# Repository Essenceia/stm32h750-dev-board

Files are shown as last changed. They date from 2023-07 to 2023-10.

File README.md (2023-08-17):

# 10 year Anniversary developpement board

Minimal custom arm m7 devloppement board designed as a 10 year anniversary present. 

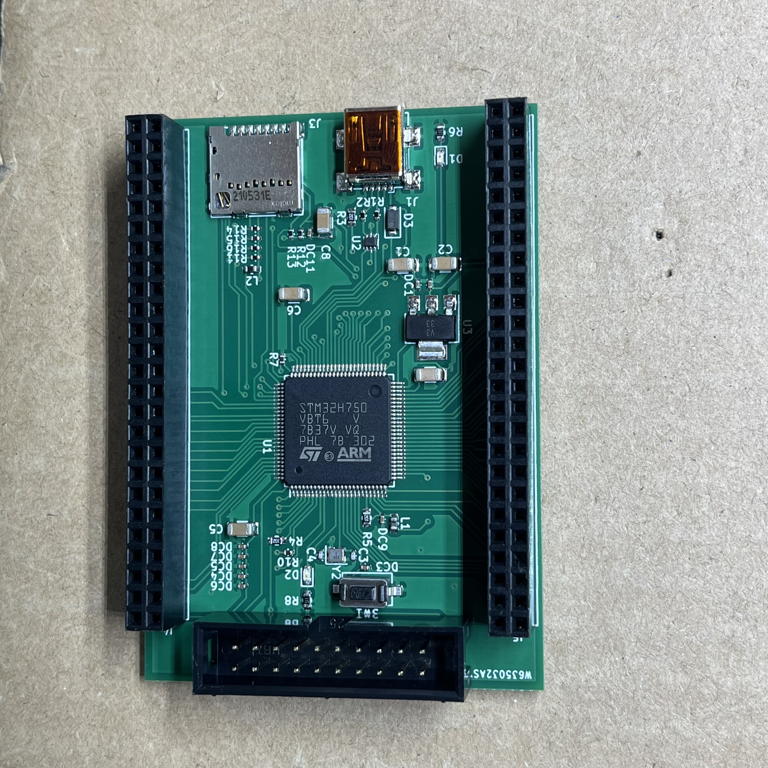
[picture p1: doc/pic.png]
picture!


Selected MCU : STM32H750VBT6TR 

MCU package :  LQFP-100 

Requirements :

- SWD debug connected with pinout compatible with native 20 pin J-Link probe

- Route all remaining mcu pins to female connectors 

## Schematics

Schematic : [schematics](/doc/schematic.pdf)

## PCB

Resulting pcb, front : 

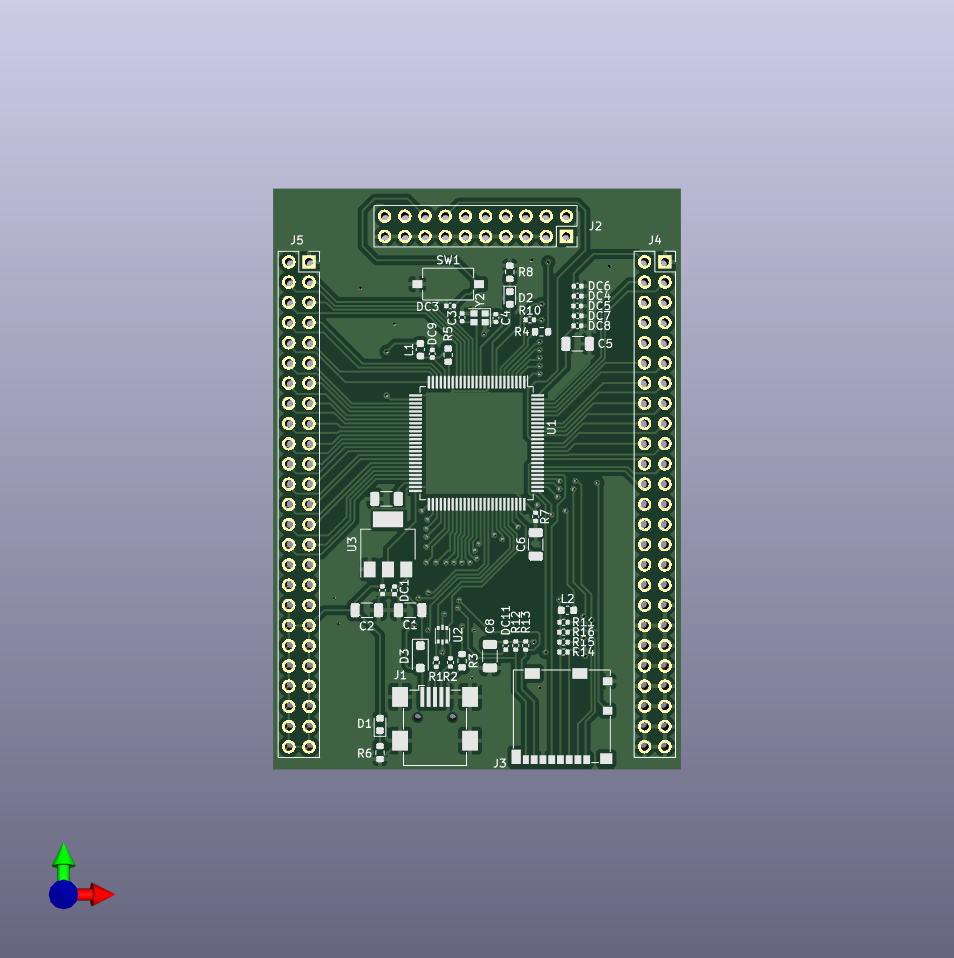
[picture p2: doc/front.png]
fount!


back :

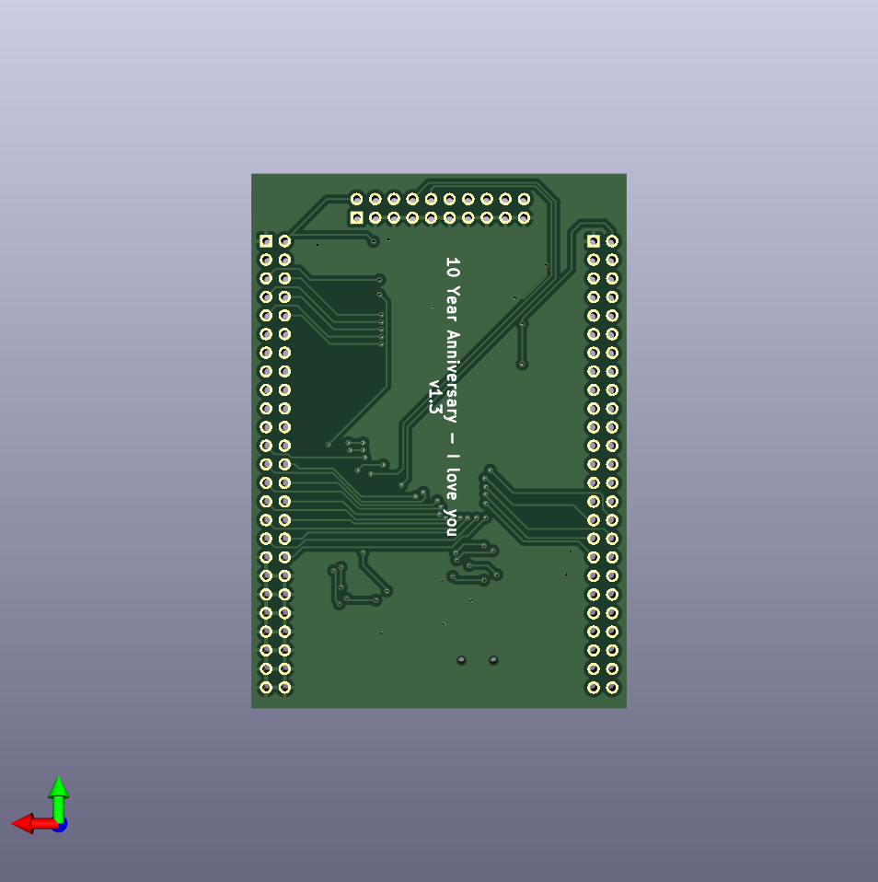
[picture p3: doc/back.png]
back!


## SWD - J-Link

SWD Connector Pinout:
connector!

The following table lists the J-Link / J-Trace SWD pinout.
|Pin|Signal|Type|Description|
|---|---|----|---|
|1|VTref|Input|This is the target reference voltage. It is used to check if the target has power, to create the logic-level reference for the input comparators and to control the output logic levels to the target. It is normally fed from Vdd of the target board and must not have a series resistor.|
|2|Vsupply|NC|This pin is not connected in J-Link. It is reserved for compatibility with other equipment. Connect to Vdd or leave open in target system.|
|3|Not used|NC|This pin is not used by J-Link. If the device may also be accessed via JTAG, this pin may be connected to nTRST, otherwise leave open.|
|5|Not used|NC|This pin is not used by J-Link. If the device may also be accessed via JTAG, this pin may be connected to TDI, otherwise leave open.|
|7|SWDIO|I/O|Single bi-directional data pin.|
|9|SWCLK|Output|Clock signal to target CPU. It is recommended that this pin is pulled to a defined state of the target board. Typically connected to TCK of target CPU.|
|11|Not used|NC|This pin is not used by J-Link. This pin is not used by J-Link when operating in SWD mode. If the device may also be accessed via JTAG, this pin may be connected to RTCK, otherwise leave open.|
|13|SWO|Input|Serial Wire Output trace port. (Optional, not required for SWD communication.)|
|15|nRESET|I/O|Target CPU reset signal. Typically connected to the RESET pin of the target CPU, which is typically called "nRST", "nRESET" or "RESET". This signal is an active low signal.|
|17|Not used|NC|This pin is not connected in J-Link.|
|19|5V-Supply|Output|This pin is used to supply power to some eval boards.|

Pins 4, 6, 8, 10, 12, 14, 16, 18, 20 are GND pins connected to GND in J-Link. They should also be connected to GND in the target system.

## Future improvements ideas

- After adding support for USB 3.0 and up switch usb b mini for thunderbolt

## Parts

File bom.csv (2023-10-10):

Item # | Designator | Qty | Manufacturer | Mfg Part # | Description / Value | Package/Footprint | Type | Your Instructions / Notes
1 | DC6,DC3,DC5,DC4,DC8,DC9,DC7,DC11,DC1,DC2 | 10 | KEMET | C0402C104K4RAC | 100nF | 0402 | SMD
2 | U3 | 1 | Texas Instruments | TLV1117-33CDCYRG3 | TLV1117-33 | SOT-223 | SMD
3 | R4,R5,R3 | 3 | SEI Stackpole | RMCF0603JJ1K00 | 1k | 0603 | SMD
4 | Y2 | 1 | ECS Inc. | ECS-250-9-37B2-CKM-TR | 25MHz 9uF | 2.0x1.6mm | SMD
5 | R15,R14,R13,R7,R16,R12,R10,R11 | 8 | YAGEO | RC0402FR-0710KL | 10k | 0402 | SMD
6 | U1 | 1 | STMicroelectronics | STM32H750VBT6TR / STM32H742VIT6 | STM32H750VBTx / STM32H742VI | LQFP-100 | QFP | MCU for v1 and v2, pin compatible
7 | J2 | 1 | On Shore Technology Inc. | 302-S201 | Conn_ARM_JTAG_SWD_20 | THD | Through Hole
8 | C8,C5,C6,C7,C1,C2 | 6 | Samsung Electro-Mechanics | CL31A476MQHNNNE | 47uF/3528 | 1206 | SMD
9 | D2,D1 | 2 | EVERLIGHT | 19-213SYGC/S530-E2/5T | LED | 0603 | SMD
10 | R1,R2 | 2 | YAGEO | RC0402FR-0722RL | 22 | 0402 | SMD
11 | R6,R8 | 2 | SEI Stackpole | RMCA0603JT510R | 510 | 0603 | SMD
12 | C4,C3 | 2 | Murata Electronics | GJM1555C1H8R0DB01D | 8pF | 0402 | SMD
13 | J3 | 1 | Molex | 1040310811 | Micro_SD_Card_Det1 |  | SMD
14 | D3 | 1 | Toshiba | CRS30I40A(TE85L,QM | SS34 | SOD-123F | SMD
15 | L1,L2 | 2 | TAI-TECH | FCM1608KF-102T02 | 1KB | 0603 | SMD
16 | SW1 | 1 | C&K | PTS636 SM43 SMTR LFS | SW_RESET | 6.0x3.5mm | SMD
17 | U2 | 1 | STMicroelectronics | USBLC6-2P6 | USBLC6-2P6 | SOT-666 | SMD
18 | J1 | 1 | Adam Tech | MUSB-B5-S-RA-SMT-PP-T/R | USB_B_Mini |  | SMD
19 | J4,J5 | 2 | Sullins Connector Solutions | PPTC252LFBN-RC | Conn_02x25_Odd_Even |  | Through Hole

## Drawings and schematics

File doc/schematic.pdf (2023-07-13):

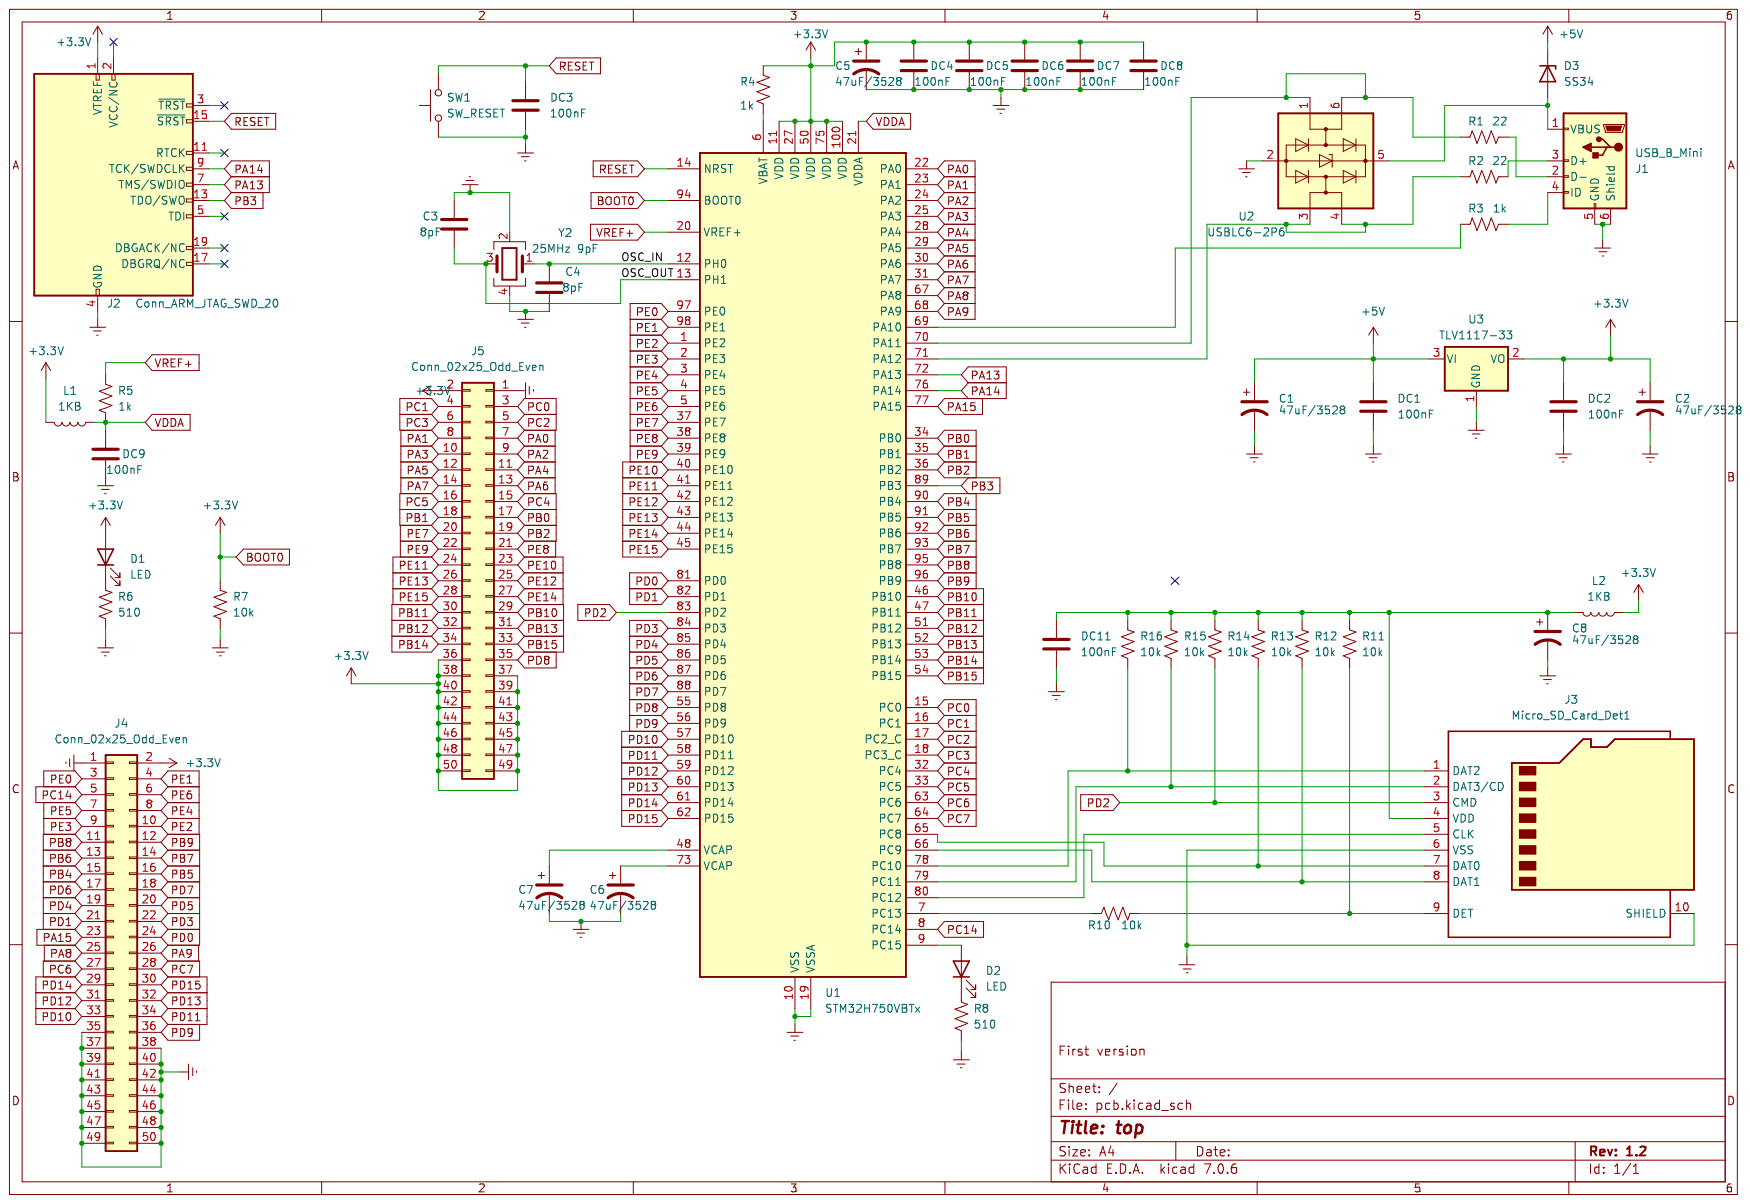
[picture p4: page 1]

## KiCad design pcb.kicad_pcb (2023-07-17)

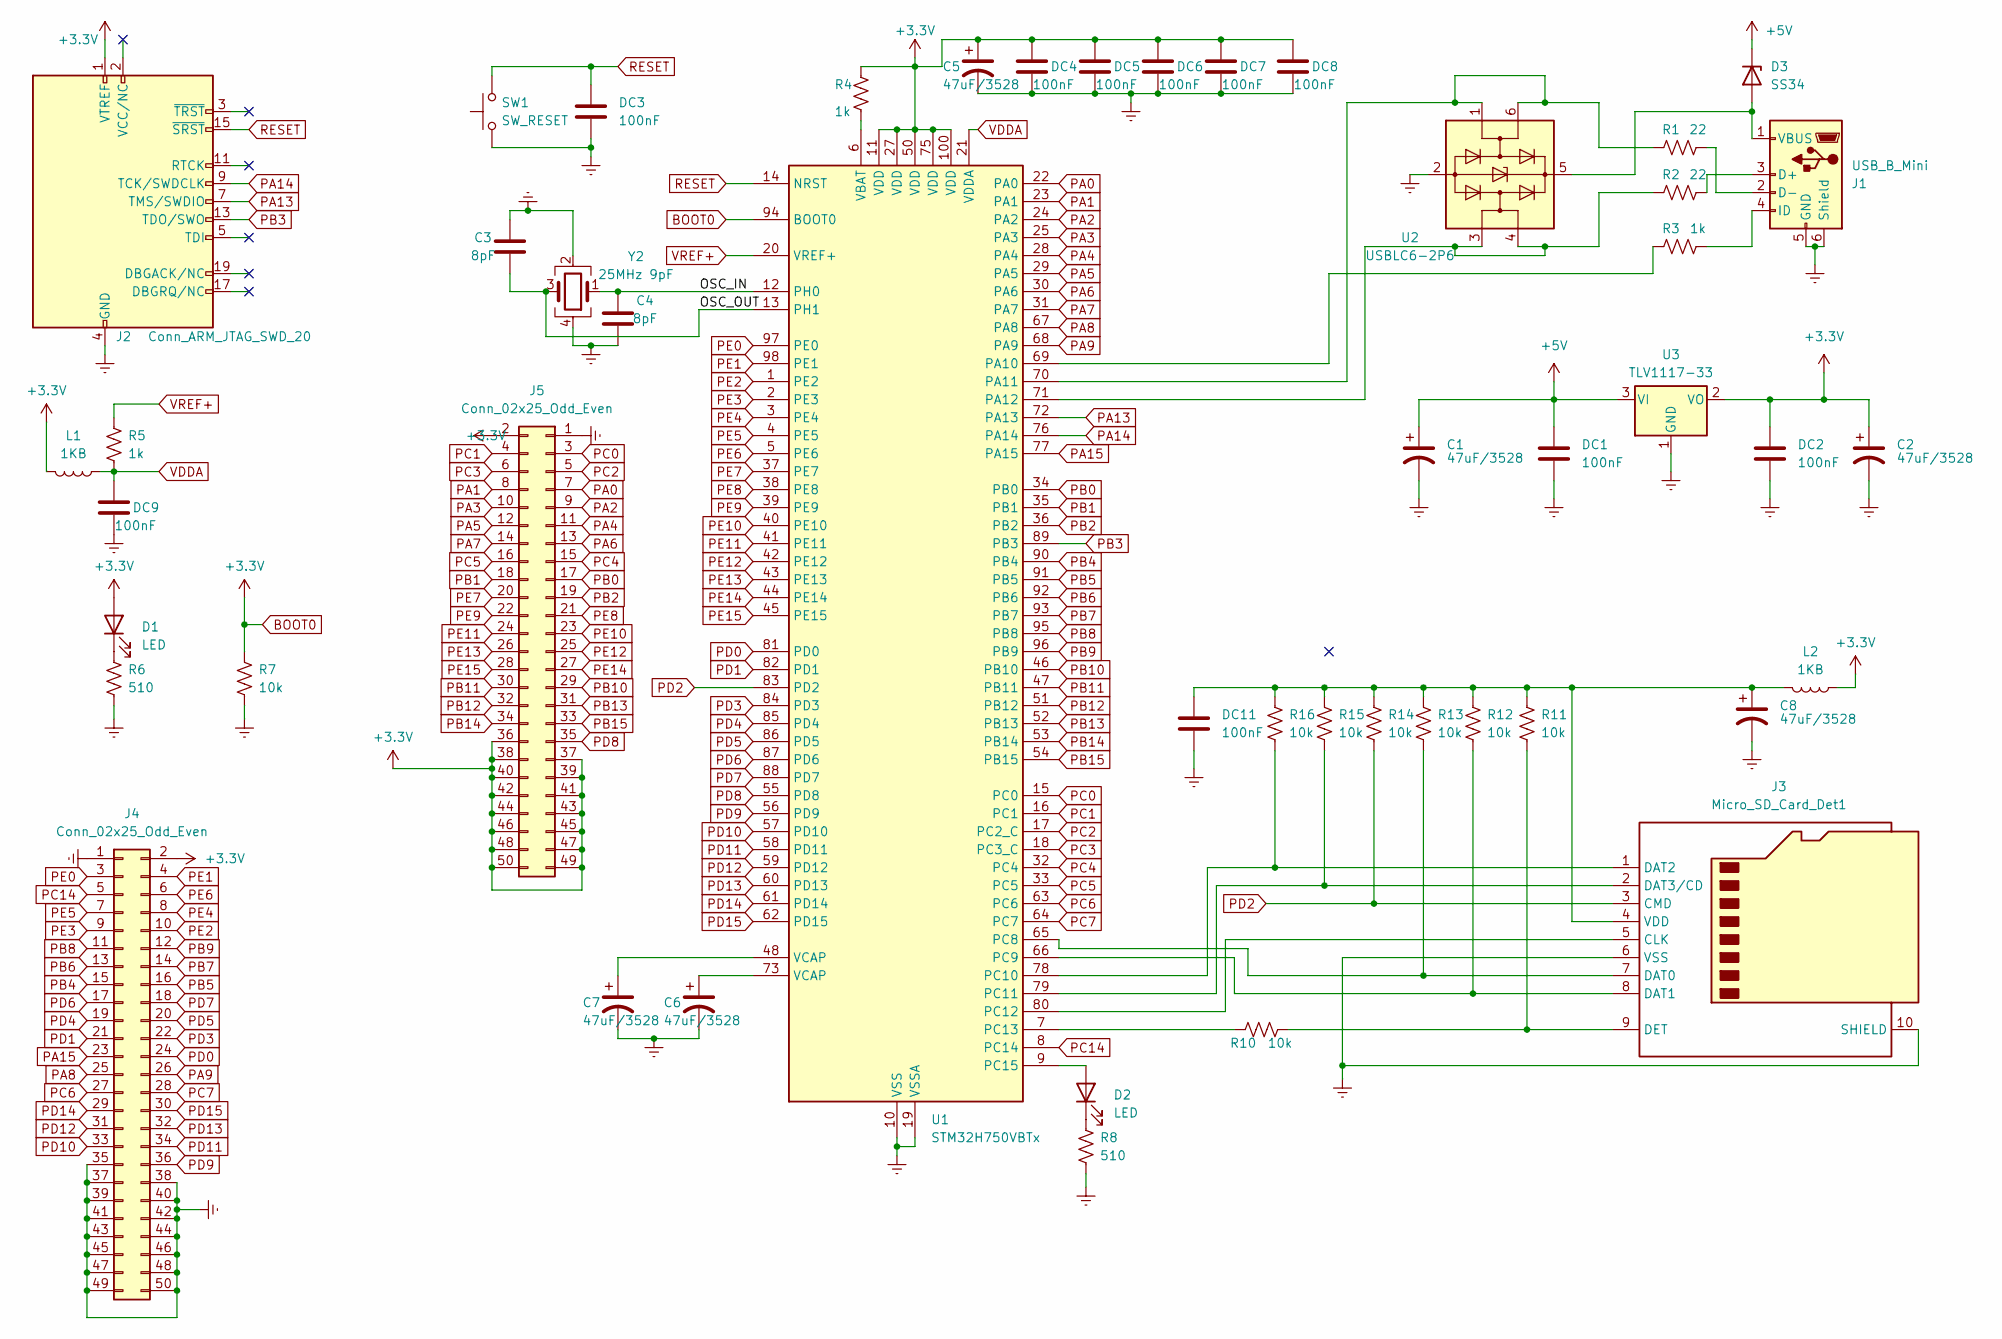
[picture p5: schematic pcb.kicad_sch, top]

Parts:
C1, C2, C5, C6, C7, C8: 47uF/3528; C_1206_3216Metric
C3, C4: 8pF; C_0402_1005Metric
D1, D2: LED; LED_0603_1608Metric
D3: SS34; D_SOD-123F
DC1, DC2, DC3, DC4, DC5, DC6, DC7, DC8, DC9, DC11: 100nF; C_0402_1005Metric
J1: USB_B_Mini; USB_Mini-B_Wuerth_65100516121_Horizontal
J2: Conn_ARM_JTAG_SWD_20; PinSocket_2x10_P2.54mm_Vertical
J3: Micro_SD_Card_Det1; microSD_HC_Molex_104031-0811
J4, J5: Conn_02x25_Odd_Even; PinSocket_2x25_P2.54mm_Vertical
L1, L2: 1KB; L_0603_1608Metric
R1, R2: 22; R_0402_1005Metric
R3, R4, R5: 1k; R_0603_1608Metric
R6, R8: 510; R_0603_1608Metric
R7, R10, R11, R12, R13, R14, R15, R16: 10k; R_0402_1005Metric
SW1: SW_RESET; SW_Tactile_SPST_NO_Straight_CK_PTS636Sx25SMTRLFS
U1: STM32H750VBTx; LQFP-100_14x14mm_P0.5mm
U2: USBLC6-2P6; SOT-666
U3: TLV1117-33; SOT-223
Y2: 25MHz 9pF; Crystal_SMD_2016-4Pin_2.0x1.6mm

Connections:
+5V: C1.1, D3.1 (K), DC1.1, U3.3 (VI)
/OSC_IN: C4.1, U1.12 (PH0), Y2.1
/OSC_OUT: C3.2, U1.13 (PH1), Y2.3
BOOT0: C2.1, C5.1, D1.2 (A), DC2.1, DC4.1, DC5.1, DC6.1, DC7.1, DC8.1, J2.1 (VTREF), J4.2, J5.2, J5.36, J5.37, J5.38, J5.39, J5.40, J5.41, J5.42, J5.43, J5.44, J5.45, J5.46, J5.47, J5.48, J5.49, J5.50, L1.2, L2.2, R4.1, R7.1, U1.11 (VDD), U1.27 (VDD), U1.50 (VDD), U1.75 (VDD), U1.94 (BOOT0), U1.100 (VDD), U3.2 (VO)
Earth: C1.2, C2.2, C3.1, C4.2, C5.2, C6.2, C7.2, C8.2, DC1.2, DC2.2, DC3.2, DC4.2, DC5.2, DC6.2, DC7.2, DC8.2, DC9.2, DC11.2, J1.5 (GND), J1.6 (Shield), J2.4 (GND), J2.6 (GND), J2.8 (GND), J2.10 (GND), J2.12 (GND), J2.14 (GND), J2.16 (GND), J2.18 (GND), J2.20 (GND), J3.6 (VSS), J3.10 (SHIELD), J4.1, J4.35, J4.37, J4.38, J4.39, J4.40, J4.41, J4.42, J4.43, J4.44, J4.45, J4.46, J4.47, J4.48, J4.49, J4.50, J5.1, R6.2, R7.2, R8.2, SW1.1, U1.10 (VSS), U1.19 (VSSA), U1.26 (VSS), U1.49 (VSS), U1.74 (VSS), U1.99 (VSS), U2.2 (GND), U3.1 (GND), Y2.2, Y2.4
unnamed: C6.1, U1.73 (VCAP)
unnamed: C7.1, U1.48 (VCAP)
unnamed: D1.1 (K), R6.1
unnamed: D2.2 (A), U1.9 (PC15)
unnamed: D2.1 (K), R8.1
unnamed: D3.2 (A), J1.1 (VBUS), U2.5 (VBUS)
unnamed: J1.3 (D+), R2.2
unnamed: J1.2 (D-), R1.2
unnamed: J1.4 (ID), R3.2
unnamed: J3.5 (CLK), U1.80 (PC12)
unnamed: J3.7 (DAT0), R13.2, U1.65 (PC8)
unnamed: J3.8 (DAT1), R12.2, U1.66 (PC9)
unnamed: J3.1 (DAT2), R16.2, U1.78 (PC10)
unnamed: J3.2 (DAT3/CD), R15.2, U1.79 (PC11)
unnamed: J3.9 (DET), R10.2, R11.2
unnamed: C8.1, DC11.1, J3.4 (VDD), L2.1, R11.1, R12.1, R13.1, R14.1, R15.1, R16.1
unnamed: R3.1, U1.69 (PA10)
unnamed: R1.1, U1.70 (PA11), U2.1 (I/O1), U2.6 (I/O1)
unnamed: R2.1, U1.71 (PA12), U2.3 (I/O2), U2.4 (I/O2)
unnamed: R10.1, U1.7 (PC13)
unnamed: R4.2, U1.6 (VBAT)
PA0: J5.7, U1.22 (PA0)
PA1: J5.8, U1.23 (PA1)
PA2: J5.9, U1.24 (PA2)
PA3: J5.10, U1.25 (PA3)
PA4: J5.11, U1.28 (PA4)
PA5: J5.12, U1.29 (PA5)
PA6: J5.13, U1.30 (PA6)
PA7: J5.14, U1.31 (PA7)
PA8: J4.25, U1.67 (PA8)
PA9: J4.26, U1.68 (PA9)
PA13: J2.7 (TMS/SWDIO), U1.72 (PA13)
PA14: J2.9 (TCK/SWDCLK), U1.76 (PA14)
PA15: J4.23, U1.77 (PA15)
PB0: J5.17, U1.34 (PB0)
PB1: J5.18, U1.35 (PB1)
PB2: J5.19, U1.36 (PB2)
PB3: J2.13 (TDO/SWO), U1.89 (PB3)
PB4: J4.15, U1.90 (PB4)
PB5: J4.16, U1.91 (PB5)
PB6: J4.13, U1.92 (PB6)
PB7: J4.14, U1.93 (PB7)
PB8: J4.11, U1.95 (PB8)
PB9: J4.12, U1.96 (PB9)
PB10: J5.29, U1.46 (PB10)
PB11: J5.30, U1.47 (PB11)
PB12: J5.32, U1.51 (PB12)
PB13: J5.31, U1.52 (PB13)
PB14: J5.34, U1.53 (PB14)
PB15: J5.33, U1.54 (PB15)
PC0: J5.3, U1.15 (PC0)
PC1: J5.4, U1.16 (PC1)
PC2: J5.5, U1.17 (PC2_C)
PC3: J5.6, U1.18 (PC3_C)
PC4: J5.15, U1.32 (PC4)
PC5: J5.16, U1.33 (PC5)
PC6: J4.27, U1.63 (PC6)
PC7: J4.28, U1.64 (PC7)
PC14: J4.5, U1.8 (PC14)
PD0: J4.24, U1.81 (PD0)
PD1: J4.21, U1.82 (PD1)
PD2: J3.3 (CMD), R14.2, U1.83 (PD2)
PD3: J4.22, U1.84 (PD3)
PD4: J4.19, U1.85 (PD4)
PD5: J4.20, U1.86 (PD5)
PD6: J4.17, U1.87 (PD6)
PD7: J4.18, U1.88 (PD7)
PD8: J5.35, U1.55 (PD8)
PD9: J4.36, U1.56 (PD9)
PD10: J4.33, U1.57 (PD10)
PD11: J4.34, U1.58 (PD11)
PD12: J4.31, U1.59 (PD12)
PD13: J4.32, U1.60 (PD13)
PD14: J4.29, U1.61 (PD14)
PD15: J4.30, U1.62 (PD15)
PE0: J4.3, U1.97 (PE0)
PE1: J4.4, U1.98 (PE1)
PE2: J4.10, U1.1 (PE2)
PE3: J4.9, U1.2 (PE3)
PE4: J4.8, U1.3 (PE4)
PE5: J4.7, U1.4 (PE5)
PE6: J4.6, U1.5 (PE6)
PE7: J5.20, U1.37 (PE7)
PE8: J5.21, U1.38 (PE8)
PE9: J5.22, U1.39 (PE9)
PE10: J5.23, U1.40 (PE10)
PE11: J5.24, U1.41 (PE11)
PE12: J5.25, U1.42 (PE12)
PE13: J5.26, U1.43 (PE13)
PE14: J5.27, U1.44 (PE14)
PE15: J5.28, U1.45 (PE15)
RESET: DC3.1, J2.15 (~SRST), SW1.2, U1.14 (NRST)
VDDA: DC9.1, L1.1, R5.2, U1.21 (VDDA)
VREF+: R5.1, U1.20 (VREF+)

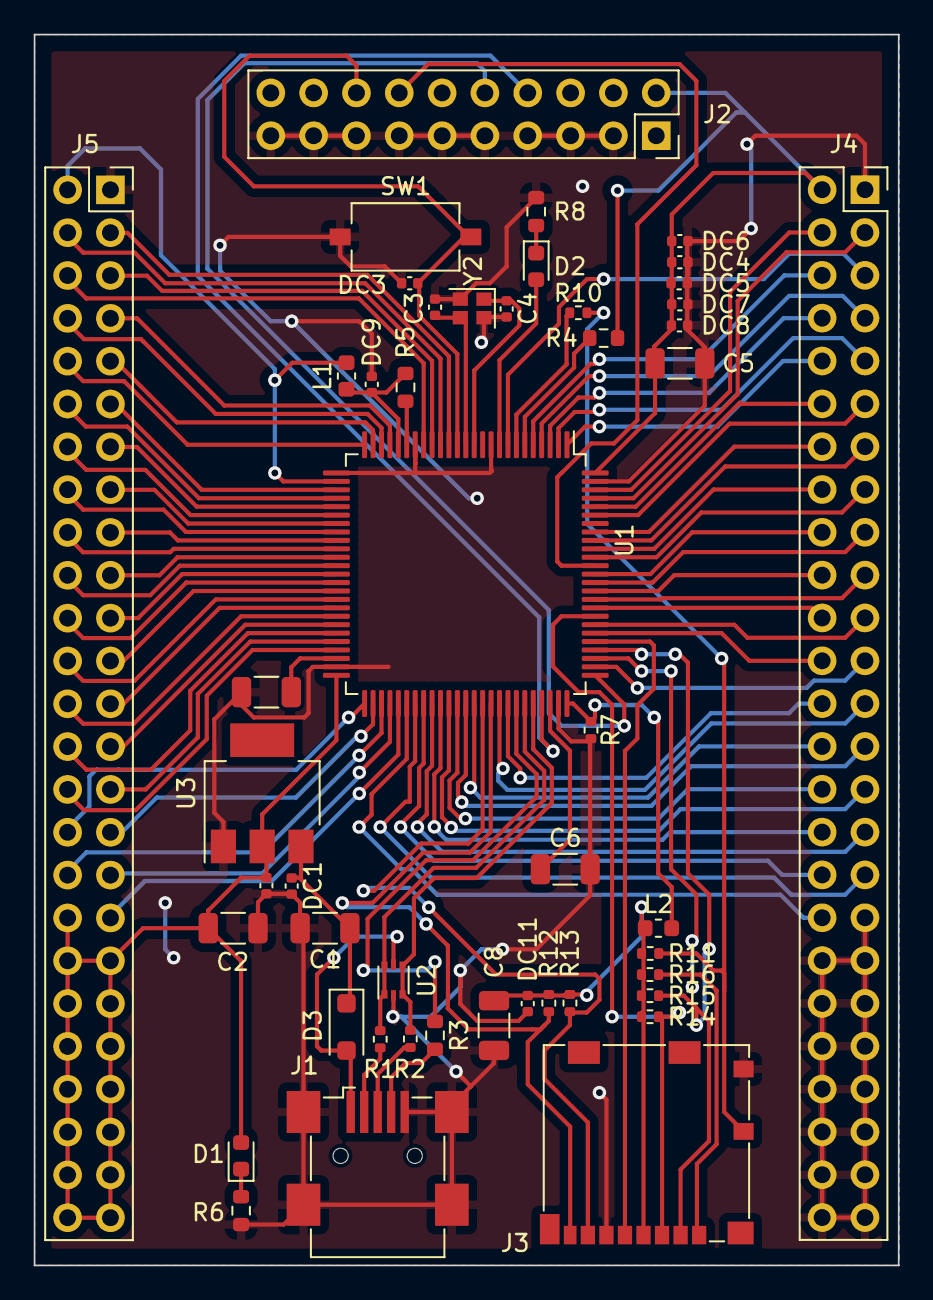
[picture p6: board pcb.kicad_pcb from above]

Board: 2 copper layers, 51.2 x 73.0 mm, 48 parts (0 on the bottom side), 99 nets.

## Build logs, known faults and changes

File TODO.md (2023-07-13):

# TODO list

## Schematic

[x] USB, provides main power

[x] Power 5V to 3.3V

[x] Oscillator 

[x] Reset ( button ? ) 

~~[ ] Flash memory~~

[x] MicroSD slot

[x] Power LED

~~[ ] Oscillator LED~~

[x] J-Link connector

[x] GPIO connectors

## PCB

[x] Route 

[x] Create bill of material

[ ] Order mounted

[ ] Rework dimentions to 5.0 x 8.0

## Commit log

2023-07-09 MCU: Selected target MCU stm32h750
2023-07-09 TODO: Add todolist
    [pcb.kicad_pcb, pcb.kicad_sch]
2023-07-10 KICAD: Update project files
    [pcb.kicad_sch]
2023-07-11 SCH: Update schematics, added everything appart from gpio pin header
    [pcb.kicad_sch]
2023-07-11 SCH: Schematic, no gpio connector
    [pcb.kicad_sch]
2023-07-12 SCH: Schematic mostly finished, missing pin connectors
    [pcb.kicad_pcb, pcb.kicad_sch]
2023-07-13 ROUTE: Routing finished, still needs to be re-worked but functionality is in place
    [pcb.kicad_pcb, pcb.kicad_sch]
2023-07-13 PCB: Routing finished, first version
    [pcb.kicad_pcb, pcb.kicad_sch]
2023-07-14 PCB: Updated footprint of JTAG connector
    [pcb.kicad_pcb, pcb.kicad_sch]
2023-07-14 DOC: Update pcb
2023-07-14 BOM: Added bill of material
    [bom.csv, pcb.kicad_pcb]
2023-07-14 GBR: Added gebber and drill files
    [pcb-B_Cu.gbr, pcb-B_Mask.gbr, pcb-B_Paste.gbr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]
2023-07-14 BOM: Updates BOM to remove out of stock parts, switched out reset switch, new footprint SPST-NO 3.5x6.0mm, moved it away from connector due to it's higher profile
    [pcb-B_Cu.gbr, pcb-B_Mask.gbr, pcb-B_Paste.gbr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]
2023-07-14 PCB: Modified back silkscreen
    [pcb-B_Cu.gbr, pcb-B_Mask.gbr, pcb-B_Paste.gbr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]
2023-07-14 DOC: Added 3d pcb view
2023-07-17 PCB: Fixed clearance violations
    [pcb-B_Cu.gbr, pcb-B_Mask.gbr, pcb-B_Paste.gbr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]
2023-07-22 ASSEMBLY: Added position file for pick and place
2023-08-17 DOC: Added picture of finished board, fount
2023-10-10 BOM: Updated bom, corrected item 5, 10 and 14 <- using wrong package, add mention of MCU for revision 2
    [bom.csv]
2023-10-10 BOM: Correct footprint for item 14 sod-123 -> sod-123f
    [bom.csv]
2023-10-10 BOM: Clean bom, line skip causing missalignement fixed
    [bom.csv]
